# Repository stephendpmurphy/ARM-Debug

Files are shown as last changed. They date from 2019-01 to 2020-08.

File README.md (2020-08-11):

# ARCHIVED - ARM Debug Board


## This project has been archived, and is being redesigned in KiCAD. The project can be found here: [swd-debug](https://github.com/stephendpmurphy/swd-debug)

This debug board allows two unused traces of a 10pin JTAG/SWD connector (Pins 7 & 9) to be broken out and used for a UART RX & TX line from the target MCU. These UART lines can be used by the Target to send debug print statements through the programming connector, to the USB bridge, and then displayed on a PC terminal. This is useful since board space is no longer needed on the target for any sort of extra headers or test pads for debug data.

All components are included via a managed library on my account. Create an issue on this repo to request access.

Note: This can only be used with Targets that use SWD as the programming interface. A different board will need to be made in the case the pinout changes of the Samtech Cortex header (TPI, SPI, etc.)

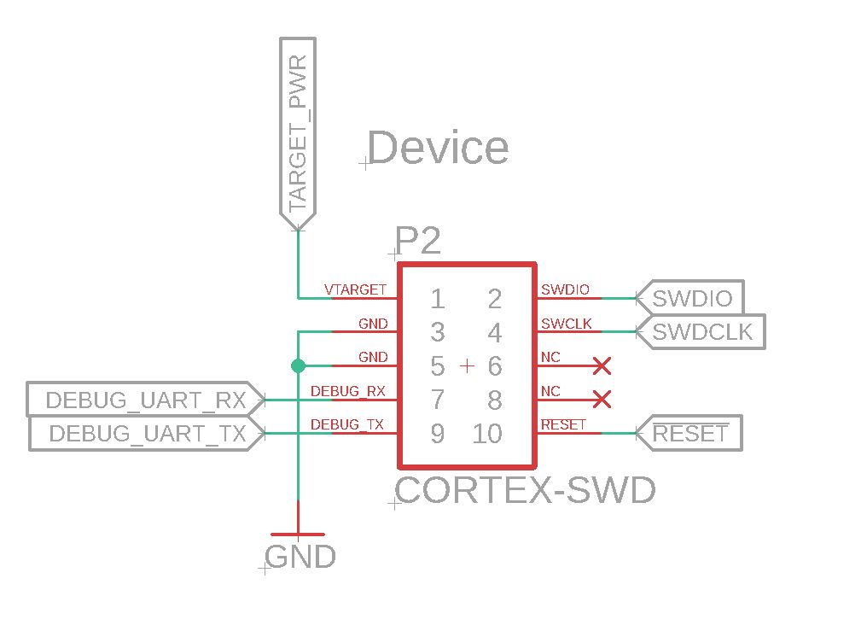
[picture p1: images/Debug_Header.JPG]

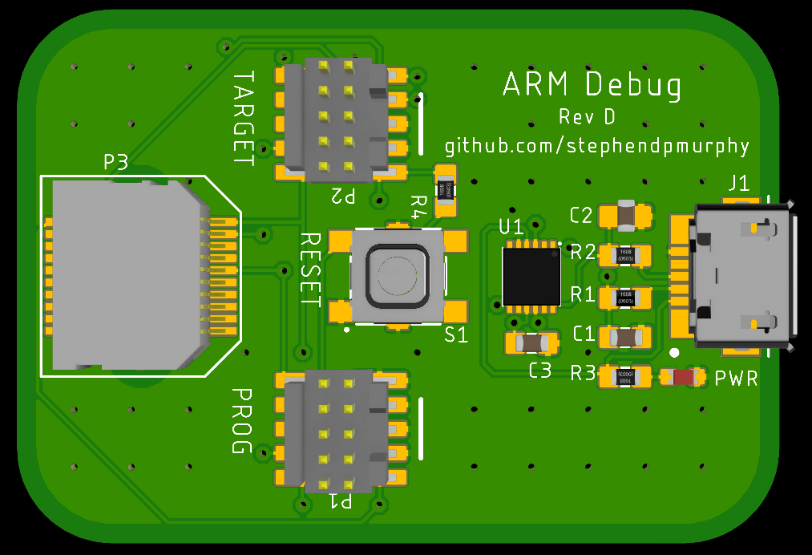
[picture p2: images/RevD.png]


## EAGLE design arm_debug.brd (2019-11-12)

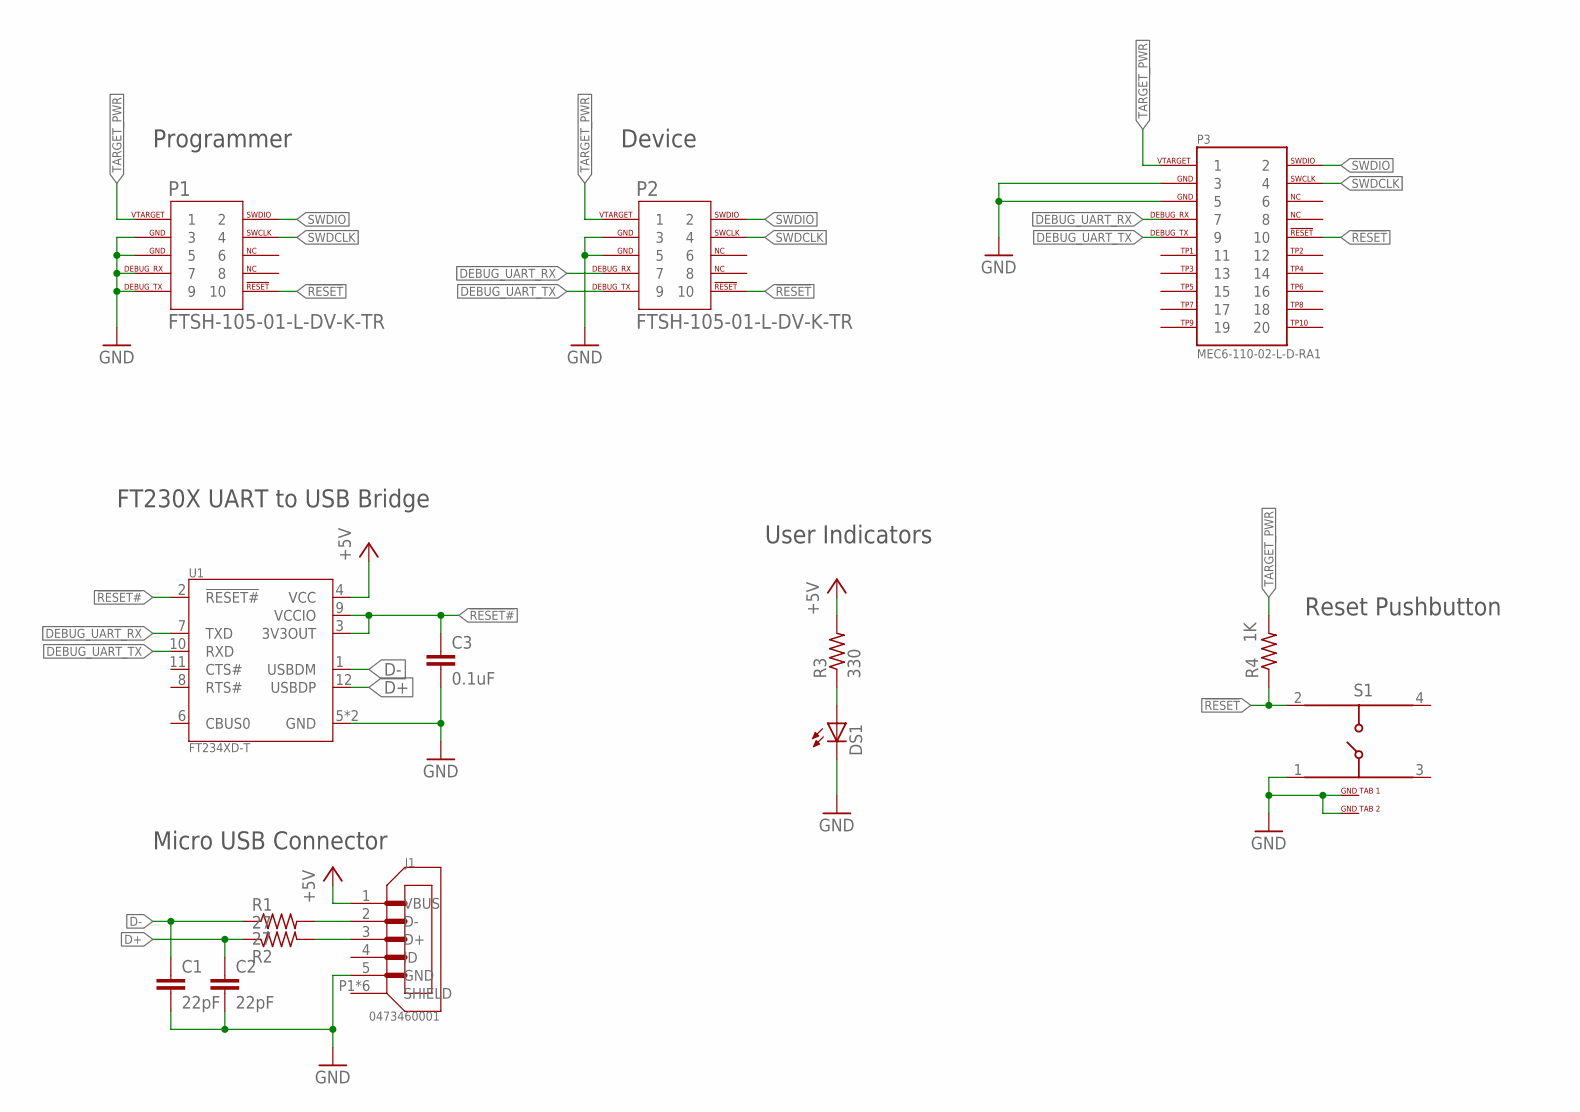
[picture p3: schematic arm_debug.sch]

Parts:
C1, C2: 22pF; M0603
C3: 0.1uF; M0603
DS1: LED0603; 0603
J1: 0473460001; 047346-0001
P1, P2: FTSH-105-01-L-DV-K-TR; SAMTEC_FTSH-105-01-L-DV-K
P3: MEC6-110-02-L-D-RA1; MEC6-110-02-X-D-RAX-F
R1, R2: 27; M0603
R3: 330; M0603
R4: 1K; M0603
S1: 431181015816
U1: FT234XD-T; DFN-12

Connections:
!RESET: P1.10, P2.10, P3.10, R4.1, S1.2
!RESET#: C3.1, U1.2 (!RESET#), U1.3 (3V3OUT), U1.9 (VCCIO)
+5V: J1.1 (VBUS), R3.2, U1.4 (VCC)
D+: C2.1, R2.1, U1.12 (USBDP)
D-: C1.1, R1.1, U1.1 (USBDM)
DEBUG_UART_RX: P2.7, P3.7, U1.7 (TXD)
DEBUG_UART_TX: P2.9, P3.9, U1.10 (RXD)
GND: C1.2, C2.2, C3.2, DS1.C, J1.5 (GND), P1.3, P1.5, P1.7, P1.9, P2.3, P2.5, P3.3, P3.5, S1.1, S1.GND1 (6), S1.GND2 (5), U1.5 (GND), U1.13 (GND)
unnamed: J1.2 (D-), R1.2
unnamed: DS1.A, R3.1
unnamed: J1.3 (D+), R2.2
SWDCLK: P1.4, P2.4, P3.4
SWDIO: P1.2, P2.2, P3.2
TARGET_PWR: P1.1, P2.1, P3.1, R4.2

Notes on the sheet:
Programmer
Device
Micro USB Connector
FT230X UART to USB Bridge
User Indicators
Reset Pushbutton

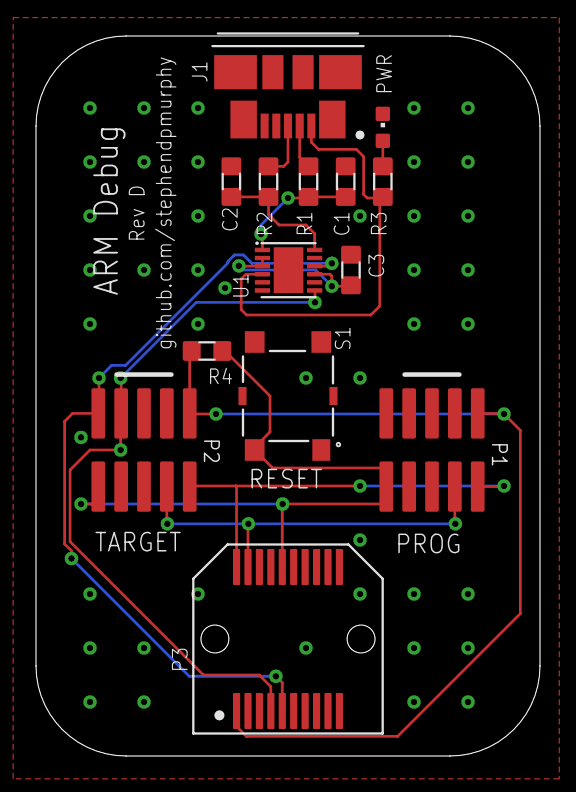
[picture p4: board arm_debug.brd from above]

Board: 2 copper layers, 28.0 x 40.0 mm, 14 parts (0 on the bottom side), 14 nets.

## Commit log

2018-05-19 Adding Rev A
    [arm_debug.brd, arm_debug.sch]
2018-05-19 Adding pictures of board and schematic
2018-05-19 Adding schematic PDF
2018-05-20 Fixing airwire between 5V LED and resistor
    [arm_debug.brd]
2018-05-28 Saving place.. currently working on Rev B
    [arm_debug.brd, arm_debug.sch]
2018-08-19 Committing RevB
    [arm_debug.GBL, arm_debug.GBO, arm_debug.GBP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]
2019-01-05 Commiting RevC
    [arm_debug.GBL, arm_debug.GBO, arm_debug.GBP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]
2019-04-21 Adding MEC connector for edge card connectors
    [arm_debug.brd, arm_debug.sch]
2019-04-21 Fixed DRC error with VIA too close to trace
    [arm_debug.brd]
2019-10-29 Fixing issue with reversed USB Data plus and minus pins
    [arm_debug.brd, arm_debug.sch]
2019-11-12 Seperating passive components into individual managed libraries
    [arm_debug.brd, arm_debug.sch]

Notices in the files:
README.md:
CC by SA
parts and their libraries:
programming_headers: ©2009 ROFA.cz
